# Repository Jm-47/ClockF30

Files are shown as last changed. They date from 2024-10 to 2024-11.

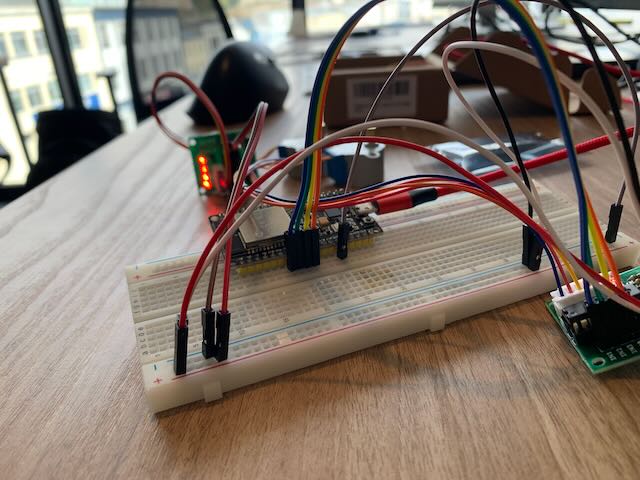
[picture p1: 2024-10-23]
images/IMG_1590.jpeg

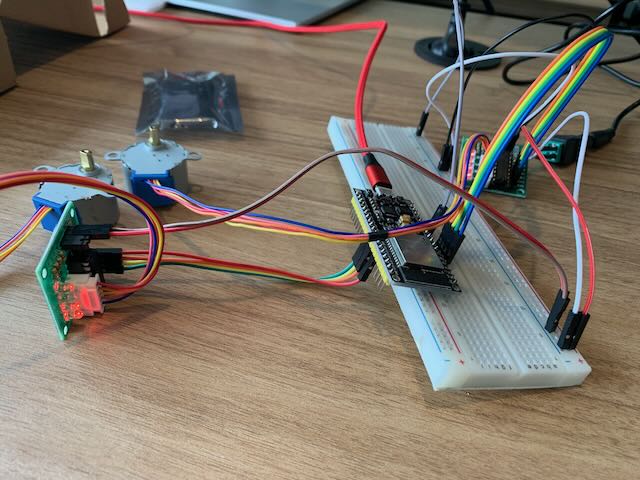
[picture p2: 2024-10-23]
images/IMG_1589.jpeg

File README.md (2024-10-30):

# ClockF30

## ESP 32
### Board name for Arduino IDE
`NodeMCU-32S`
### Pins
https://cdn.shopify.com/s/files/1/1509/1638/files/ESP-32_NodeMCU_Developmentboard_Pinout.pdf?v=1609851295

[ESP-32_NodeMCU_Developmentboard_Pinout.pdf](images/ESP-32_NodeMCU_Developmentboard_Pinout.pdf)

## Stepper motor
https://www.digikey.fr/fr/htmldatasheets/production/1839399/0/0/1/28byj-48

## Manuel utilisateur

- Se connecte à `wififourneau` au démarrage. 

### Calibration

- Positionner les aiguilles sur 12 avec les deux potentiomètres
- Maintenir le bouton de gauche appuyé et en même temps appuyer l'un des deux autres.

### Mode horloge

- Bouton du milieu

### Mode 6:02

- Bouton de droite

### Mode libre

- Tourner les potentiomètres.

Quand on passe en mode horloge ou 6:02, les potentiomètres sont désactivés. Ils se réactivent quand ils repassent par la position neutre.

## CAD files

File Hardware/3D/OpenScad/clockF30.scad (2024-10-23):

include <gear-lib.scad>

thickness = 2;

entraxe = 35;
desaxe = 8;

// Axe du moteur
h_bit = 6;
r_bit = 2.7;
meplat = 3.3;

//h_head = 3;
//r_head = 4.5;

// Boulon
r_shaft = 2;

// Gears
n_teeth = 20;
gear_size = 17.4;


module Text(letter, size, height, valign) {
    // convexity is needed for correct preview
    // since characters can be highly concave
    linear_extrude(height = height, convexity = 0)
        text(letter,
        size = size,
        font = "Allerta Stencil",
        //font="Monaco",                 
        halign = "center",
        valign = valign);
}

module support(height) {
        union() {
            cylinder(h = height, r = r_shaft + 2, $fn = 30);
            cylinder(h = 5, r1 = r_shaft + 5, r2=r_shaft + 2, $fn = 30);
        }
}

module support_double(height) {
    support(height);
    translate([0, entraxe, 0]) support(height);

    // Location of the engine axle
    if (show_engine_axle) color("white") translate([8, entraxe / 2, height - h_bit - 4]) engine_axle();
}
module engine_axle() {
    intersection() {
        cylinder(h = h_bit, r = r_bit, $fn = 30);
        translate([-meplat / 2, -r_bit - .5, 0]) cube([meplat, r_bit * 2 + 1, h_bit + 2]);
    }
}

module engine_axle_plug() {
    cylinder(h = h_bit, r = r_bit + 2, $fn = 30);
}


support = true;
gear1 = false;
gear2 = false;
axle = false;

show_engine_axle = false;
 

if (support) {
    difference() {
        union() {
            translate([-20, -10]) cube([70, 100, 2]);
            support_double(16);
            translate([40, entraxe, 0]) rotate([0, 0, 180]) support_double(14);
            translate([40 - 8, entraxe / 2, 2]) translate([0, 0, -.5]) cylinder(h = 1, r1 = 2, r2 = 0, $fn = 30);
        }
        union() {
            translate([8, -5, -1]) cylinder(h = 4, r = 2.2, $fn = 30);
            
            #translate([8, entraxe / 2, -1]) cylinder(h = 4, d = 5.25, $fn = 30);
            
            translate([0, 0, -1]) union() {
                cylinder(h = 50, r = 2.2, $fn = 30);
                cylinder(h = 4, r = 4, $fn = 6);
            }
            
            translate([0, entraxe, -1]) union() {
                cylinder(h = 50, r = 2.2, $fn = 30);
                cylinder(h = 4, r = 4, $fn = 6);
            }

            translate([40, 0, -1]) union() {
                cylinder(h = 50, r = 2.2, $fn = 30);
                cylinder(h = 4, r = 4, $fn = 6);
            }

            translate([40, entraxe, -1]) union() {
                cylinder(h = 50, r = 2.2, $fn = 30);
                cylinder(h = 4, r = 4, $fn = 6);
            }

            rotate([0, 0, 90]) translate([40, 10, -1]) Text("Le Fourneau a 30 ans !", 6, 4);
        }
    }
}

// First gear
if (gear1) color("red") translate([40 - 8, entraxe / 2, 2])
    difference() {
        union() {
            rotate([0, 0, 360 / (n_teeth * 2)]) gear(n_teeth, 8, gear_size);
            translate([0, 0, .5]) engine_axle_plug();
        }
        union() {
            translate([0, 0, -.5]) cylinder(h = 1, r1 = 3, r2 = 0, $fn = 30);
            translate([0, 0, 1]) engine_axle();
        }
    }

// Second gear
if (gear2) color("blue") translate([8, entraxe / 2, 2])
    difference() {
        union() {
            gear(n_teeth, 8, gear_size);
            translate([0, 0, -15]) cylinder(h = 16, d = 5, $fn = 30);
        }
        translate([0, 0, -16]) cylinder(h = 20, r = 2, $fn = 30);
    }

// Direct axle
if (axle) color("green")   translate([8, entraxe / 2, 2])
    difference() {
        union() {
            translate([0, 0, 2]) engine_axle_plug();
            translate([0, 0, -24]) cylinder(h = 30, r = 1.8, $fn = 30);
        }
        translate([0, 0, 3.5]) engine_axle();
    }

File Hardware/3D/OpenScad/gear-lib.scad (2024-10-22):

/**************** GEARS ********************
gear(nb-teeth,thikness,scale); // min 10
********************************************/

module gr_1(n=0,thk=0){

    r = n*1.5;
  
module tooth(){
    sz = 5;
    sx = 3;
    th = thk;
    of = 5;
        
    hull(){
    translate([0,0,th/2])
    cube([sz,sz,th],center=true); 
    translate([of,0,th/2])
    cube([sx,sx,th],center=true);}}

    for(i=[0:n]) //n is number of teeth
    rotate([0,0,i*360/n])
    translate([r,0,0]) 
    tooth();
    
    cylinder(r=r,h=thk);}

module gear(n=0,thk=0,sc=0){
    sc = sc*0.0204;
    scale(sc)
    gr_1(n=n,thk=thk);}


/********** WORM **********/
    
module grx(nn=0,thkk=0){
  
module tootx(){
    sz = 5;
    sx = 3;
    th = thkk-1.8;
    of = 5;
        rotate([90,0,0])
    hull(){
    translate([0,0,th/2])
    cube([sz,sz,th],center=true); 
    translate([of,0,th/2])
    cube([sx,sx,th],center=true);}}

    for (n = [1 : 450]){
    rotate([0,0,n*4]){
        translate([10,0,n*0.12])
        tootx();
    }}
   // color("yellow")
    translate([0,0,-2.4])
    cylinder(d=16,h=59);
    }
    
module worm(scl=0){
    nn=5;
    thkk=3;
    scl = scl*0.0204;
    scale(scl)
    grx(nn=nn,thkk=thkk);}
    

/**************** GEARS *******************/

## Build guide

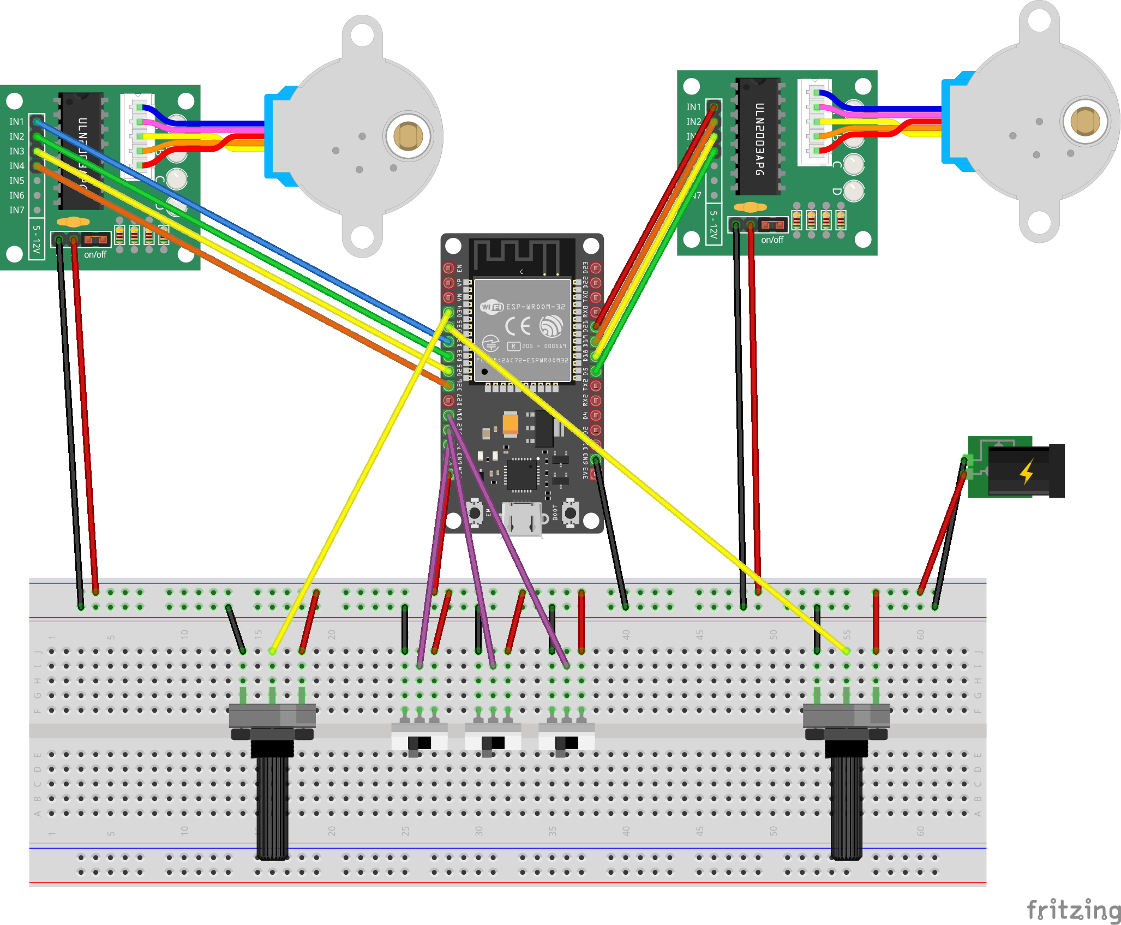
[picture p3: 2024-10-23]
Hardware/Wiring/ClockF30_schema_fritzing_bb.png

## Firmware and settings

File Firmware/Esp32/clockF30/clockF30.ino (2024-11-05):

#include <AccelStepper.h>
#include <WiFi.h>
#include <time.h>


// WiFi credentials
const char* ssid = "wififourneau";
const char* password = "capucins2020";

// NTP Server
#define NTP_SERVER "pool.ntp.org"
#define EUROPE_PARIS "CET-1CEST,M3.5.0/02,M10.5.0/03"

#define motorPin21 32  // IN1 on ULN2003 ==> Blue   on 28BYJ-48
#define motorPin22 33  // IN2 on ULN2004 ==> Pink   on 28BYJ-48
#define motorPin23 25  // IN3 on ULN2003 ==> Yellow on 28BYJ-48
#define motorPin24 26  // IN4 on ULN2003 ==> Orange on 28BYJ-48

#define motorPin11 5   // IN1 on ULN2003 ==> Blue   on 28BYJ-48
#define motorPin12 18  // IN2 on ULN2004 ==> Pink   on 28BYJ-48
#define motorPin13 19  // IN3 on ULN2003 ==> Yellow on 28BYJ-48
#define motorPin14 21  // IN4 on ULN2003 ==> Orange on 28BYJ-48

#define hourPotPin 34
#define minPotPin 35

#define buttonPin1 12
#define buttonPin2 13
#define buttonPin3 14

#define MAX_POT 4096
#define MIDDLE_POT 2048
#define SENSITIVITY 256

#define REVOLUTION 4096

#define MAX_SPEED 800.0
#define ACCELERATION 500.0


// Potentiometers
#define ARRAY_SIZE 8
int readingIndex = 0;
int hourPotReading[ARRAY_SIZE];
int hourPot = 0;
int minPotReading[ARRAY_SIZE];
int minPot = 0;

unsigned long lastReadingMillis;
#define READING_INTERVAL 20

boolean ignoreHourPot = false;
boolean ignoreMinPot = false;

// Mode
#define CALIBRATION 0
#define CLOCK 1
#define TWO_PAST_SIX 2
#define SPEED 3
int mode = 0;

// hand speed
float hourSpeed = 0;
float minSpeed = 0;

// Buttons
int button1 = HIGH;
int button2 = HIGH;
int button3 = HIGH;

// NOTE: The sequence 1-3-2-4 is required for proper sequencing of 28BYJ-48
AccelStepper hourStepper(AccelStepper::HALF4WIRE, motorPin11, motorPin13, motorPin12, motorPin14);
AccelStepper minStepper(AccelStepper::HALF4WIRE, motorPin21, motorPin23, motorPin22, motorPin24);

void setup() {
  Serial.begin(9600);
  while (!Serial) {
    ;  // wait for serial port to connect. Needed for native USB port only
  }
  Serial.println("Serial connected");

  // // init buttons
  pinMode(buttonPin1, INPUT_PULLUP);
  pinMode(buttonPin2, INPUT_PULLUP);
  pinMode(buttonPin3, INPUT_PULLUP);
  pinMode(hourPotPin, INPUT);
  pinMode(minPotPin, INPUT);

  // Connect to WiFi
  Serial.println("Connecting to WiFi");
  WiFi.begin(ssid, password);
  while (WiFi.status() != WL_CONNECTED) {
    delay(500);
    Serial.print(".");
  }
  Serial.println("WiFi connected");

  configTzTime(EUROPE_PARIS, NTP_SERVER);
  struct tm time_info;
  if (!getLocalTime(&time_info)) {
    Serial.println("Failed to obtain time");
  }
  Serial.println(&time_info, "%A, %B %d %Y %H:%M:%S zone %Z %z ");

  hourStepper.setSpeed(MAX_SPEED);
  hourStepper.setMaxSpeed(MAX_SPEED);
  hourStepper.setAcceleration(ACCELERATION);

  minStepper.setSpeed(MAX_SPEED);
  minStepper.setMaxSpeed(MAX_SPEED);
  minStepper.setAcceleration(ACCELERATION);

  ignoreHourPot = true;
  ignoreMinPot = true;
}

void loop() {
  // Read potentiometers
  unsigned long currentMillis = millis();
  if (currentMillis - lastReadingMillis >= READING_INTERVAL) {
    hourPotReading[readingIndex] = analogRead(hourPotPin);
    int newHourPot = mean(hourPotReading) / SENSITIVITY * SENSITIVITY;
    if (newHourPot != hourPot) {
      hourPot = newHourPot;
      Serial.print("HourPot ");
      Serial.println(hourPot);
    }

    minPotReading[readingIndex] = analogRead(minPotPin);
    int newMinPot = mean(minPotReading) / SENSITIVITY * SENSITIVITY;
    if (newMinPot != minPot) {
      minPot = newMinPot;
      Serial.print("MinPot ");
      Serial.println(minPot);
    }

    lastReadingMillis = currentMillis;
    if (++readingIndex == ARRAY_SIZE) { readingIndex = 0; }
  }

  // Read buttons
  int status = digitalRead(buttonPin1);
  if (button1 == HIGH && status == LOW) { Serial.println("Button 1 is low"); }
  if (button1 == LOW && status == HIGH) { Serial.println("Button 1 is high"); }
  button1 = status;

  status = digitalRead(buttonPin2);
  if (button2 == HIGH && status == LOW) { Serial.println("Button 2 is low"); }
  if (button2 == LOW && status == HIGH) { Serial.println("Button 2 is high"); }
  button2 = status;

  status = digitalRead(buttonPin3);
  if (button3 == HIGH && status == LOW) { Serial.println("Button 3 is low"); }
  if (button3 == LOW && status == HIGH) { Serial.println("Button 3 is high"); }
  button3 = status;

  if (button1 == LOW && button3 == HIGH && mode != CLOCK) {
    Serial.println("Clock mode");
    mode = CLOCK;
    ignoreHourPot = true;
    ignoreMinPot = true;
  }
  else if (button2 == LOW && button3 == HIGH && mode != TWO_PAST_SIX) {
    Serial.println("06:02");
    mode = TWO_PAST_SIX;
    ignoreHourPot = true;
    ignoreMinPot = true;
  }
  else if (button3 == LOW && (button1 == LOW ||button2 == LOW) && mode != CALIBRATION) {
    Serial.println("Calibration");
    mode = CALIBRATION;
    ignoreHourPot = true;
    ignoreMinPot = true;
  }

  // ------------------
  // --- Clock mode ---
  // ------------------
  if (mode == CLOCK) {
    struct tm time_info;
    if (!getLocalTime(&time_info)) {
      Serial.println("Failed to obtain time");
    }
    else {
      moveHandToPosition(&hourStepper, ((REVOLUTION * (time_info.tm_hour % 12)) / 12 +
                                        (REVOLUTION * time_info.tm_min) / 720));
      // moveHandToPosition(&minStepper, REVOLUTION * time_info.tm_sec / 60); // seconds
      moveHandToPosition(&minStepper, ((REVOLUTION * time_info.tm_min) / 60 +
                                       (REVOLUTION * time_info.tm_sec) / 3600));
    }
  }

  // -------------------------
  // --- Two past six mode ---
  // -------------------------
  if (mode == TWO_PAST_SIX) {
    moveHandToPosition(&hourStepper, REVOLUTION * 6 / 12);
    moveHandToPosition(&minStepper, REVOLUTION * 2 / 60);
  }

  // ------------------------
  // --- Calibration mode ---
  // ------------------------
  if (mode == CALIBRATION) {
    hourStepper.setCurrentPosition(0);
    minStepper.setCurrentPosition(0);
  }

  // ------------------
  // --- Speed mode ---
  // ------------------
  if (hourPot <= MIDDLE_POT) {
    if (hourSpeed != 0) {
      Serial.println("Hours pot reset");
      hourSpeed = 0;
    }
    ignoreHourPot = false;
  } else if (ignoreHourPot) {
    // Ignore
  } else {
    if (mode != SPEED) {
      Serial.println("Speed mode");
      mode = SPEED;
    }
    float speed = MAX_SPEED * (hourPot - MIDDLE_POT) / MIDDLE_POT;
    if (speed != hourSpeed) {
      hourSpeed = speed;
      Serial.print("Run hours hand at ");
      Serial.println(hourSpeed);
      }
    hourStepper.setSpeed(speed);
    if (hourSpeed > 0) {
      hourStepper.move(1000);
    } else {
      hourStepper.move(-1000);
    }
    hourStepper.runSpeed();
  }

  // Control direction and speed
  if (minPot == MIDDLE_POT) {
    if (minSpeed != 0) {
      Serial.println("Minutes pot reset");
      minSpeed = 0;
    }
    ignoreMinPot = false;
  } else if (ignoreMinPot) {
    // Ignore
  } else {
    if (mode != SPEED) {
      Serial.println("Speed mode");
      mode = SPEED;
    }
    float speed = MAX_SPEED * (minPot - MIDDLE_POT) / MIDDLE_POT;
    if (speed != minSpeed) {
      minSpeed = speed;
      Serial.print("Run minutes hand at ");
      Serial.println(minSpeed);
    }
    minStepper.setSpeed(speed);
    if (minSpeed > 0) {
      minStepper.move(1000);
    } else {
      minStepper.move(-1000);
    }
    minStepper.runSpeed();
  }
}

void moveHandToPosition(AccelStepper *stepper, int destination) {
    if (stepper->distanceToGo() == 0) {

      long currentPosition = stepper->currentPosition();

      currentPosition = currentPosition % REVOLUTION;
      stepper->setCurrentPosition(currentPosition);

      if (currentPosition != destination) {
        Serial.print("Current position ");
        Serial.print(currentPosition);

        if (destination < currentPosition) {
          stepper->setCurrentPosition(currentPosition - REVOLUTION);

          Serial.print(" new current position ");
          Serial.print(currentPosition - REVOLUTION);
        }

        Serial.print(" move to  ");
        Serial.println(destination);

        stepper->moveTo(destination);
      }
    }
    stepper->run();
}

int mean(int array[]) {
  int sum = 0;
  for (int i = 0; i < ARRAY_SIZE; i++) { sum = sum + array[i]; }
  return sum / ARRAY_SIZE;
}

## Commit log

2024-10-22 Create clockF30.scad
    Restitution des éléments
    [clockF30.scad]
2024-10-22 Restitution des éléments
    [clockF30.scad]
2024-10-22 When setting to 06:02, ignore the potentiometers until they are reset
    [clockF30.ino]
2024-10-24 Decrease sensitivity Stabilize potentiometer reading
    [clockF30.ino]
2024-10-25 Calibration = b3+b1 or b3+b2 Remove MARGIN
